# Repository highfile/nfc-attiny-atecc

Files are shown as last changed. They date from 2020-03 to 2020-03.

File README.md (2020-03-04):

# nfc-attiny-atecc
Secure element enabled nfc tag, inspired by the SiLo concept of Kong Cash

* NFC: NXP NTAG I2C plus
* Microcontroller: Attiny85V
* Secure Element: ATECC608A

Other than the microcontroller, the primary components are the same as used in Kong Cash. The assumption here (since their design is not open source) is that the mcu acts as a pass-through and doesn't require any special security features itself. All parts on this board are SOIC8 package for ease of hand soldered assembly, but all come in smaller QFN or similar packages for reduced size design.

**Update: Boards sent off for manufacture 3/4/20, COVID-19 likely to cause delays. Firmware to follow.**

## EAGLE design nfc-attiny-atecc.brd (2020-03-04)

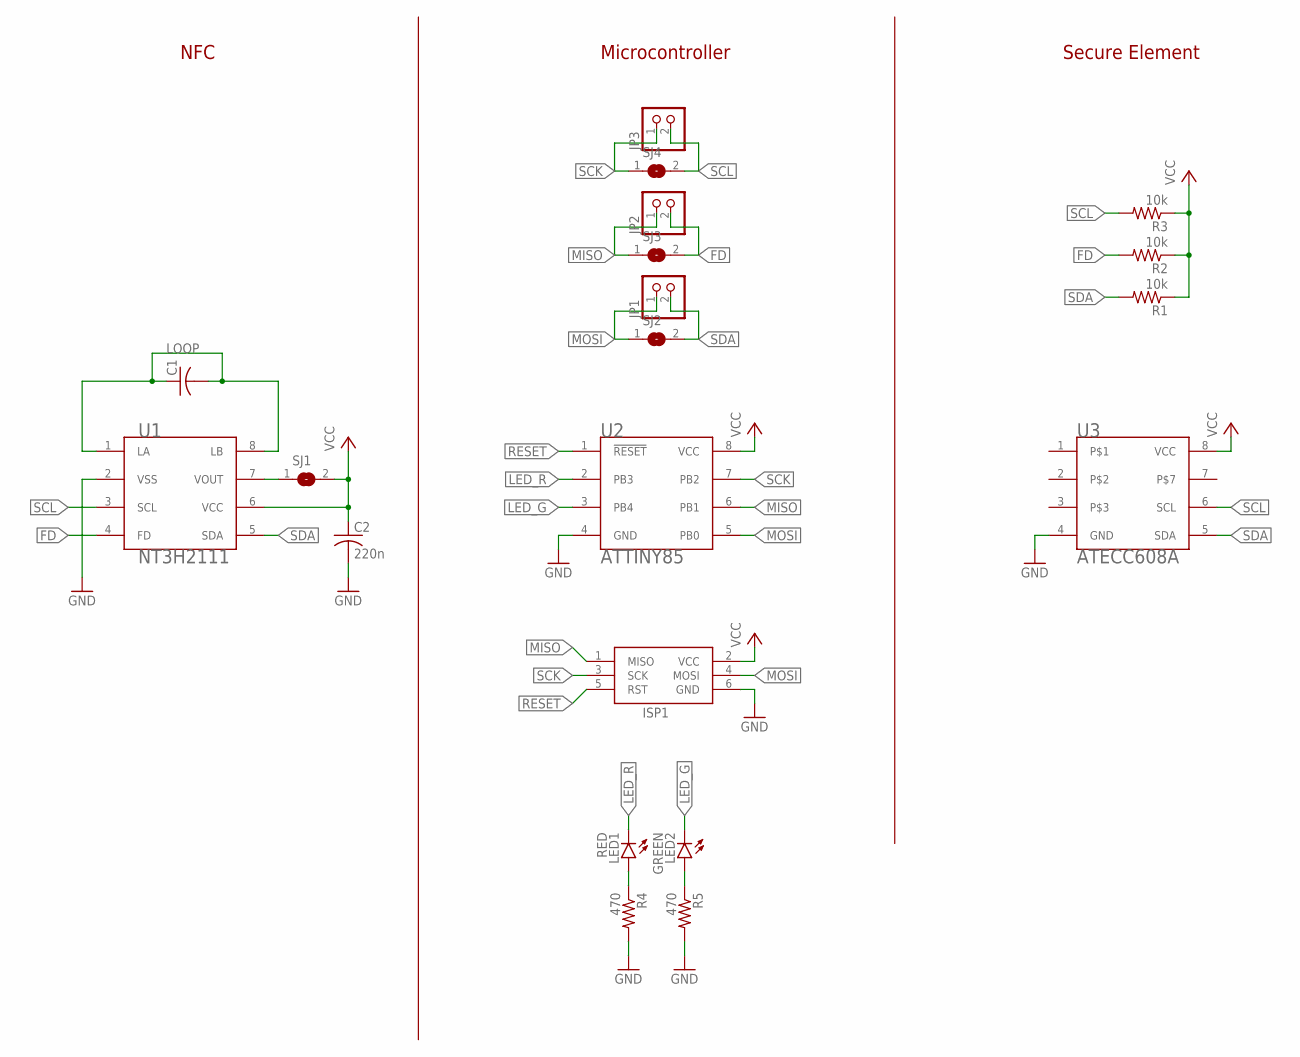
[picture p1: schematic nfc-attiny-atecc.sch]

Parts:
C1: C-USC0805; C0805
C2: 220n; C0805
ISP1: AVRISP-BOX
JP1, JP2, JP3: PINHD-1X2; 1X02
LED1: RED; CHIP-LED0805
LED2: GREEN; CHIP-LED0805
R1, R2, R3: 10k; R0805
R4, R5: 470; R0805
SJ1, SJ2, SJ3, SJ4: SJ
U1: NT3H2111; SOIC127P600X175-8N
U2: ATTINY85; SOIC127P797X215-8N
U3: ATECC608A; SOIC127P600X175-8N

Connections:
FD: JP2.2, R2.2, SJ3.2, U1.4 (FD)
GND: C2.2, ISP1.6 (GND), R4.2, R5.2, U1.2 (VSS), U2.4 (GND), U3.4 (GND)
LED_G: LED2.C, U2.3 (PB4)
LED_R: LED1.C, U2.2 (PB3)
LOOP: C1.1, C1.2, U1.1 (LA), U1.8 (LB)
MISO: ISP1.1 (MISO), JP2.1, SJ3.1, U2.6 (PB1)
MOSI: ISP1.4 (MOSI), JP1.1, SJ2.1, U2.5 (PB0)
unnamed: SJ1.1, U1.7 (VOUT)
unnamed: LED1.A, R4.1
unnamed: LED2.A, R5.1
RESET: ISP1.5 (RST), U2.1 (!RESET)
SCK: ISP1.3 (SCK), JP3.1, SJ4.1, U2.7 (PB2)
SCL: JP3.2, R3.2, SJ4.2, U1.3 (SCL), U3.6 (SCL)
SDA: JP1.2, R1.2, SJ2.2, U1.5 (SDA), U3.5 (SDA)
VCC: C2.1, ISP1.2 (VCC), R1.1, R2.1, R3.1, SJ1.2, U1.6 (VCC), U2.8 (VCC), U3.8 (VCC)

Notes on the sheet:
NFC
Microcontroller
Secure Element

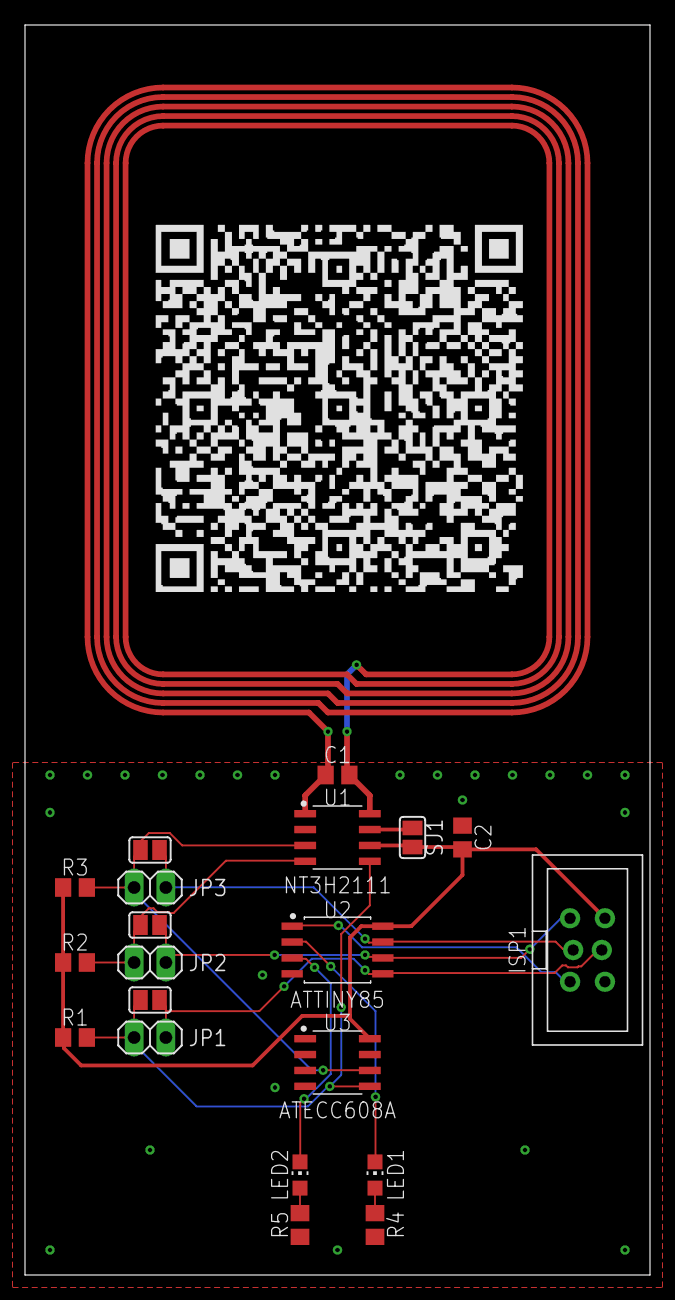
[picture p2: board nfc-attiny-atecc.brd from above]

Board: 2 copper layers, 50.0 x 100.0 mm, 20 parts (0 on the bottom side), 15 nets.
